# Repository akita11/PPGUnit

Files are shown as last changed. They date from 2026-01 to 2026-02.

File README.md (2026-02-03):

# PPG Clip

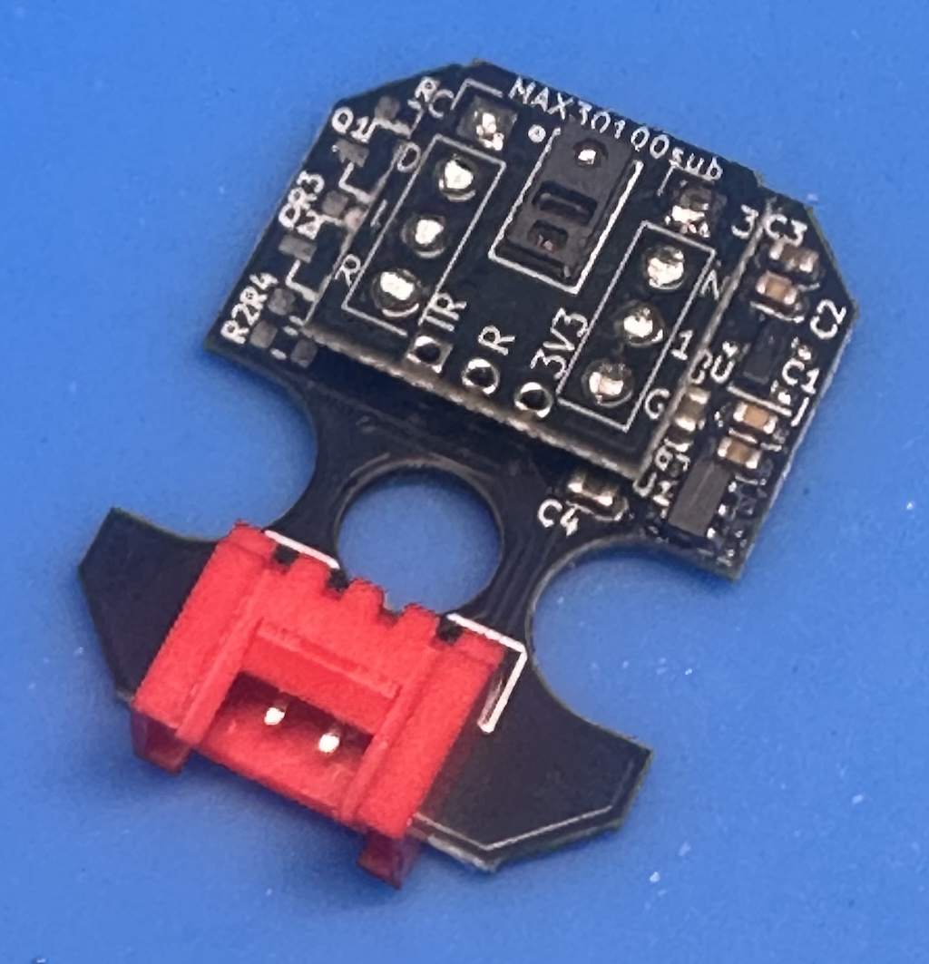
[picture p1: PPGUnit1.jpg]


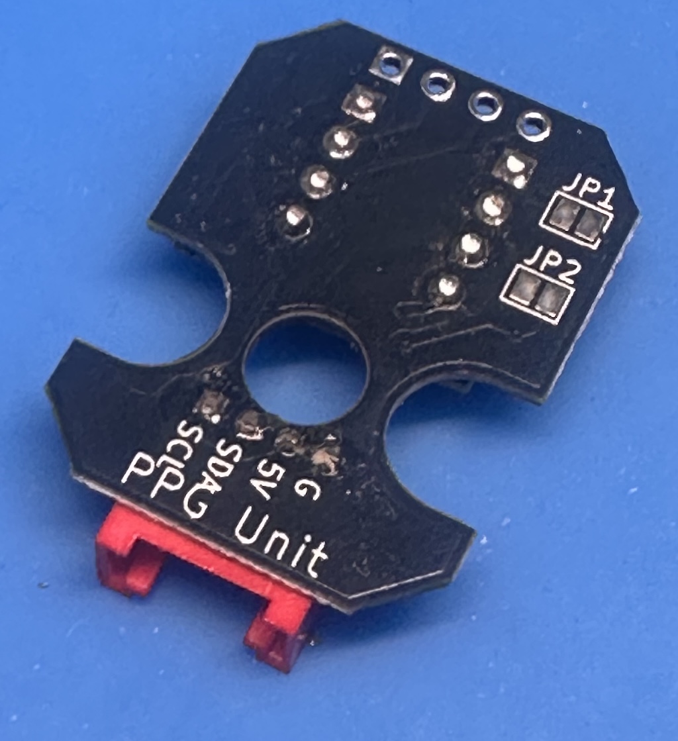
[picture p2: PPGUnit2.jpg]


[M5Stack社の心拍センサユニット](https://www.switch-science.com/products/5695)と機能的に互換のUnitです。
光学脈波(PPG)センサのMAX30100を使用し、光学脈波やSpO2、そこから心拍数の計測ができます。
また[PPG Clip部品セット](https://github.com/akita11/PPGclip)と組み合わせることで、透過型PPG計測装置をつくることができます。

※センサICのMAX30100は、再生品を使用している場合があります。基本的な測定には問題がないことは確認済みですが、新品とは多少の性能の差異がある場合があります。

## 使い方

[M5Stack社の心拍センサユニット](https://www.switch-science.com/products/5695)と機能的に互換ですので、そちらのソフトウエア(Arduino用ライブラリ、UIFlow等)がそのまま使用できます。

## 作り方

2枚の基板を、向きをあわせて、2組の4pピンヘッダではんだ付けします。
ピンヘッダの足は十分に短くカットしてください。

## 補足情報(I2C信号線について)

MAX30100のI2C信号線の端子の絶対最大定格は6.0Vです。
I2C信号線のプルアップ抵抗はGroveコネクタのVDD側(M5Stackシリーズでは5V)に接続されており、HレベルはVDD電圧（同5V）となりますが、絶対最大定格を超えません。
M5Stack社の心拍センサユニットでは、ここに電圧変換用の部品が入っていますが、I2C信号の波形を観測したところ、立ち下がり速度がかなり遅く、特に400kHz通信の場合には通信エラーが多発する現象が確認されましたので、この構成としています。

## Author

Junichi Akita (@akita11) / akita@ifdl.jp

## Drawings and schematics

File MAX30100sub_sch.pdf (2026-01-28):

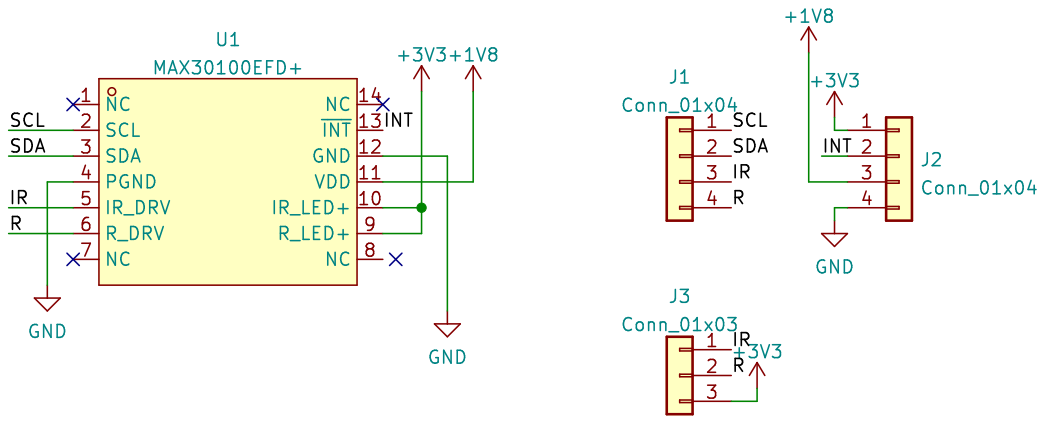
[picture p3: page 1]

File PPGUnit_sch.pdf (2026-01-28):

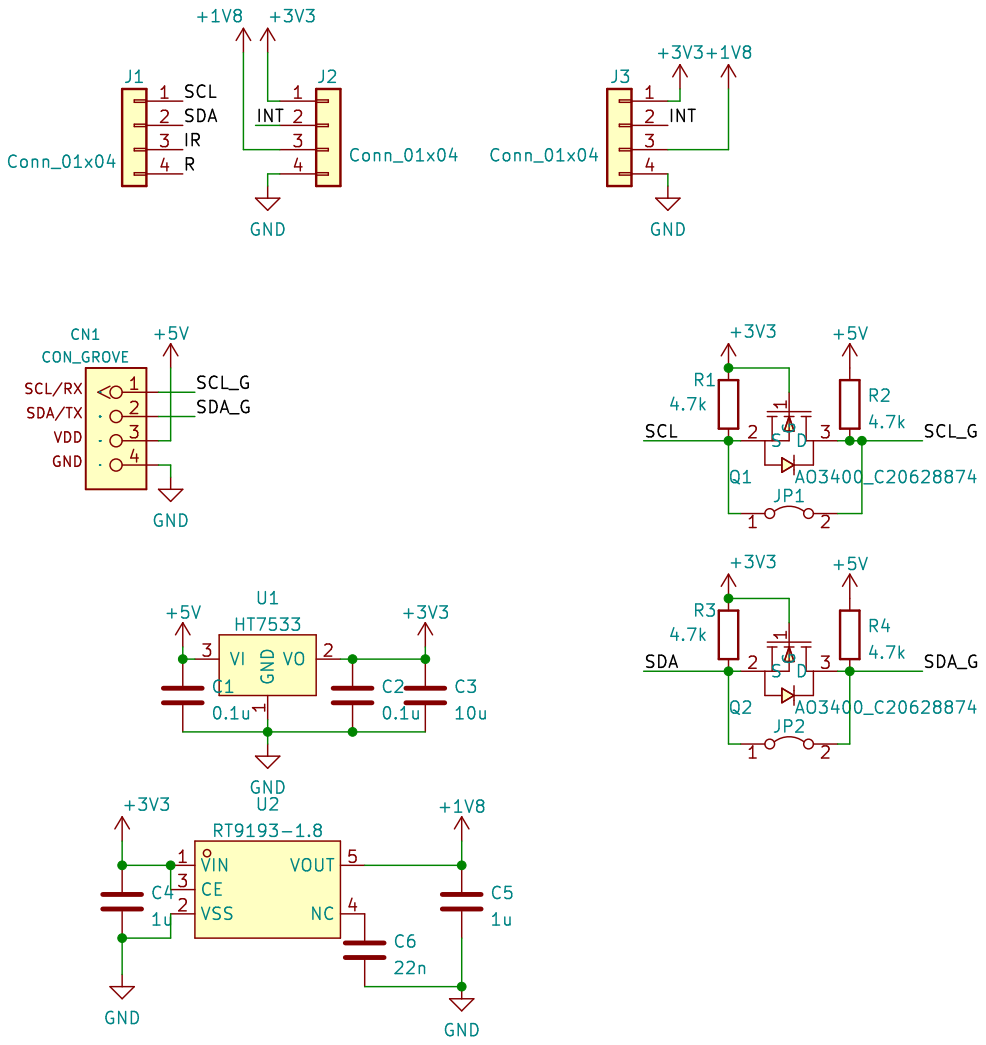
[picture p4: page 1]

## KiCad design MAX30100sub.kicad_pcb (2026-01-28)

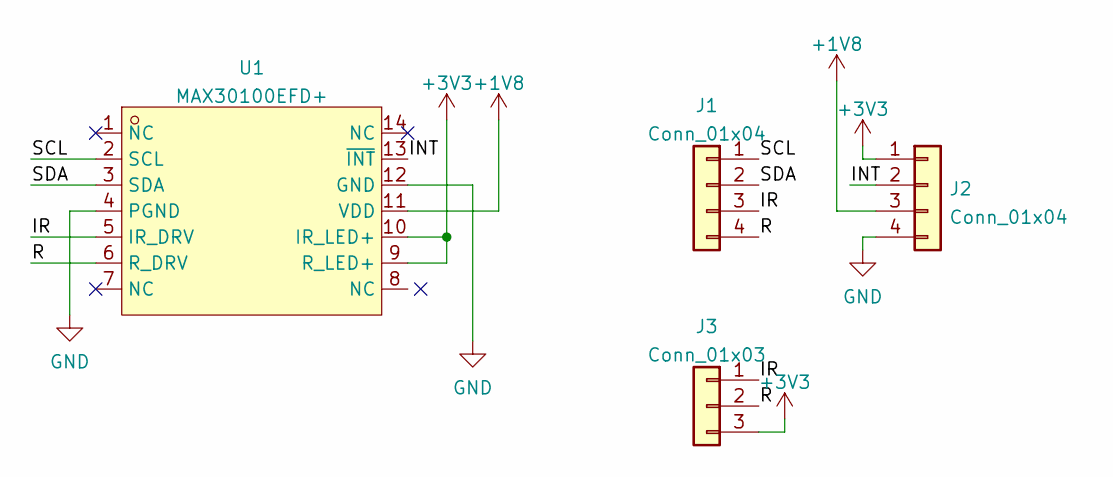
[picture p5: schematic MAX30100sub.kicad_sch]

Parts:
J1, J2: Conn_01x04; PinHeader_1x04_P2.54mm_Vertical
J3: Conn_01x03; PinSocket_1x03_P2.00mm_Vertical
U1: MAX30100EFD+; SENSOR-SMD_MAX30100EFD; LCSC Part C92512

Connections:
+1V8: J2.3, U1.11 (VDD)
+3V3: J2.1, J3.3, U1.9 (R_LED+), U1.10 (IR_LED+)
/INT: J2.2, U1.13 (~INT)
/IR: J1.3, J3.1, U1.5 (IR_DRV)
/R: J1.4, J3.2, U1.6 (R_DRV)
/SCL: J1.1, U1.2 (SCL)
/SDA: J1.2, U1.3 (SDA)
GND: J2.4, U1.4 (PGND), U1.12 (GND)

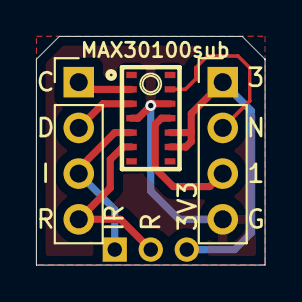
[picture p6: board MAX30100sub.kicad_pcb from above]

Board: 2 copper layers, 12.7 x 12.7 mm, 4 parts (0 on the bottom side), 8 nets.

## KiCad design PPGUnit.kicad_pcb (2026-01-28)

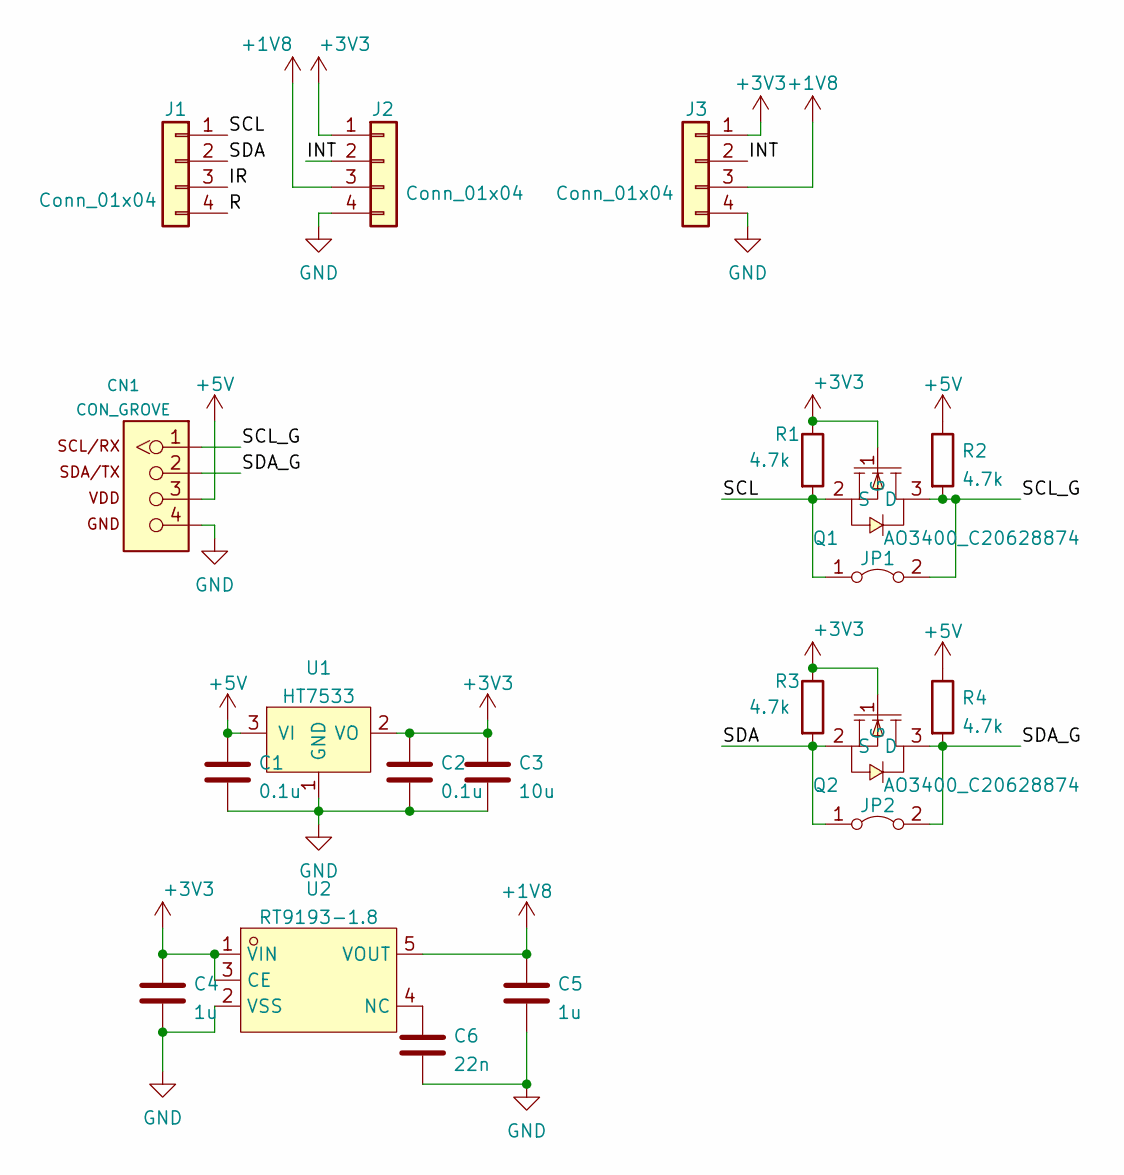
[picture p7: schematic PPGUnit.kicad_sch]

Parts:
C1, C2: 0.1u; C_0603_1608Metric
C3: 10u; C_0603_1608Metric
C4, C5: 1u; C_0603_1608Metric
C6: 22n; C_0603_1608Metric
CN1: CON_GROVE; CON_GROVE_H
J1, J2, J3: Conn_01x04; PinSocket_1x04_P2.54mm_Vertical
JP1, JP2: Jumper_2_Bridged; SolderJumper-2_P1.3mm_Bridged_Pad1.0x1.5mm
Q1, Q2: AO3400_C20628874; SOT-23-3_L2.9-W1.3-P1.90-LS2.4-BR; LCSC Part C20628874
R1, R2, R3, R4: 4.7k; R_0603_1608Metric
U1: HT7533; SOT-23
U2: RT9193-1.8; SOT-23-5_L2.9-W1.6-P0.95-LS2.8-BR; LCSC Part C22466424

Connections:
+1V8: C5.1, J2.3, J3.3, U2.5 (VOUT)
+3V3: C2.1, C3.1, C4.1, J2.1, J3.1, Q1.1 (G), Q2.1 (G), R1.1, R3.1, U1.2 (VO), U2.1 (VIN), U2.3 (CE)
+5V: C1.1, CN1.3, R2.1, R4.1, U1.3 (VI)
/INT: J2.2, J3.2
/IR: J1.3
/R: J1.4
/SCL: J1.1, JP1.1 (A), Q1.2 (S), R1.2
/SCL_G: CN1.1, JP1.2 (B), Q1.3 (D), R2.2
/SDA: J1.2, JP2.1 (A), Q2.2 (S), R3.2
/SDA_G: CN1.2, JP2.2 (B), Q2.3 (D), R4.2
GND: C1.2, C2.2, C3.2, C4.2, C5.2, C6.2, CN1.4, J2.4, J3.4, U1.1 (GND), U2.2 (VSS)
unnamed: C6.1, U2.4 (NC)

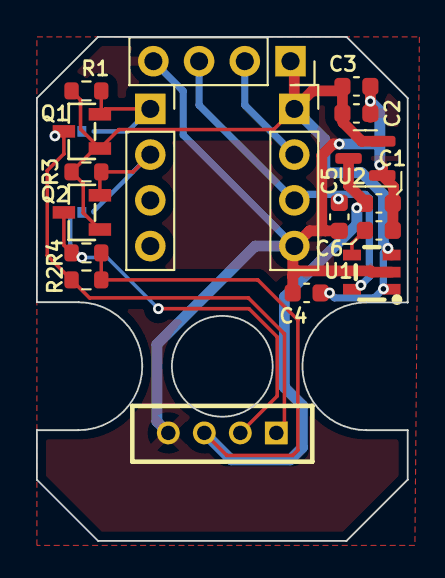
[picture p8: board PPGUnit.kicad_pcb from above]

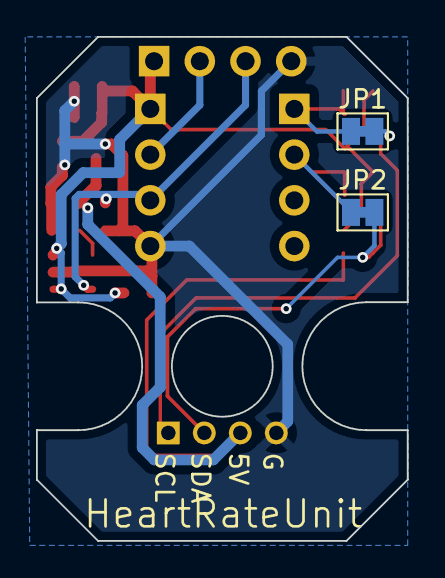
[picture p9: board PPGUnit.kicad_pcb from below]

Board: 2 copper layers, 20.6 x 28.0 mm, 20 parts (2 on the bottom side), 10 nets.

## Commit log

2026-01-28 initial commit (no photo)
    [MAX30100sub.kicad_pcb, MAX30100sub.kicad_sch, PPGUnit.kicad_pcb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]
2026-02-03 Fix typo in I2C signal line referene
